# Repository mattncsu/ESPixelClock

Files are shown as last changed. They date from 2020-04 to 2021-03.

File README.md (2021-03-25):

# ESPixelClock
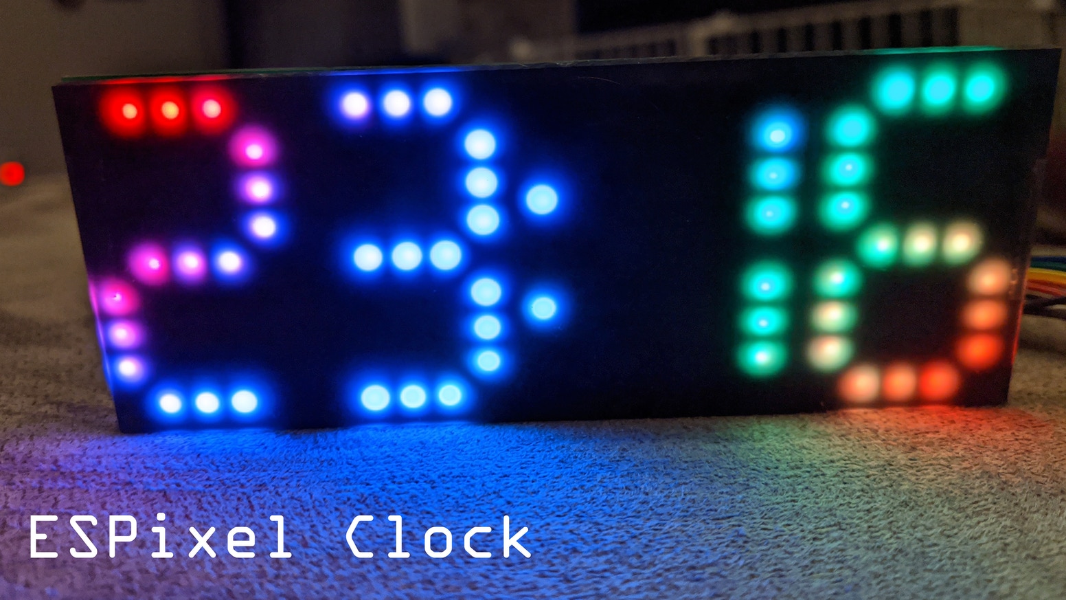
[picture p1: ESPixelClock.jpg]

Collection of code examples for the ESPixelClock

[This](https://github.com/mattncsu/ESPixelClock/tree/master/examples/ESPixelClock) is the code that comes pre-flashed on clocks that shipped with an ESP32 attached.

For those starting off with a bare board, I recommend taking a look at the examples in the [simple](https://github.com/mattncsu/ESPixelClock/tree/master/examples/simple) folder because they'll be easier to adapt to other microcontrollers.

ESP-ready version is now available on Amazon: https://www.amazon.com/ESPixel-Pixel-Based-Segment-Display-Raspberry/dp/B08TGLGM2F 
ESP-32 included version on Amazon: https://www.amazon.com/ESPixel-Clock-Pixel-Based-Segment-Display/dp/B08XQ449VJ

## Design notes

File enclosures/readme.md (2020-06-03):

Here is a place to post cases, enclosures, and other miscellaneous bits.

[DXF](hardware/Neo7Segment3535.dxf) and [STL](hardware/ESPixelClock_Board.stl) files are posted in the hardware folder to facilitate new designs.

[Light Diffuser](https://www.thingiverse.com/thing:4218698): This offsets the LEDs from the opaqe screen a bit causing the individual pixels to blur together:
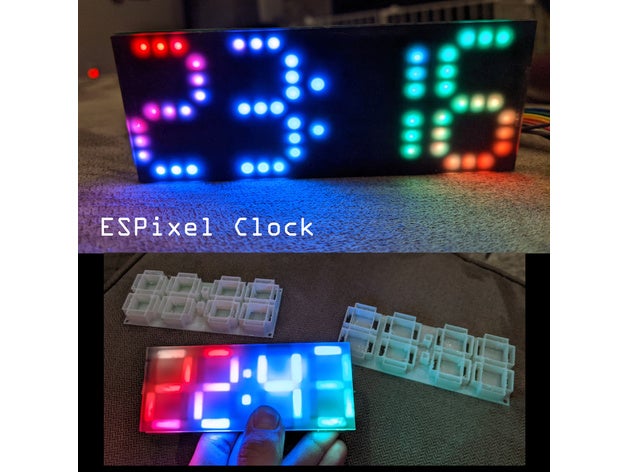
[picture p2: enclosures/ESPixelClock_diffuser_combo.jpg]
diffuser


[Simple Enclosure](https://www.thingiverse.com/thing:4145818): Simple enclosure design by Jason Coon:


[ESPixelClock Case](https://www.thingiverse.com/thing:4355887): Nice design by Tedder:


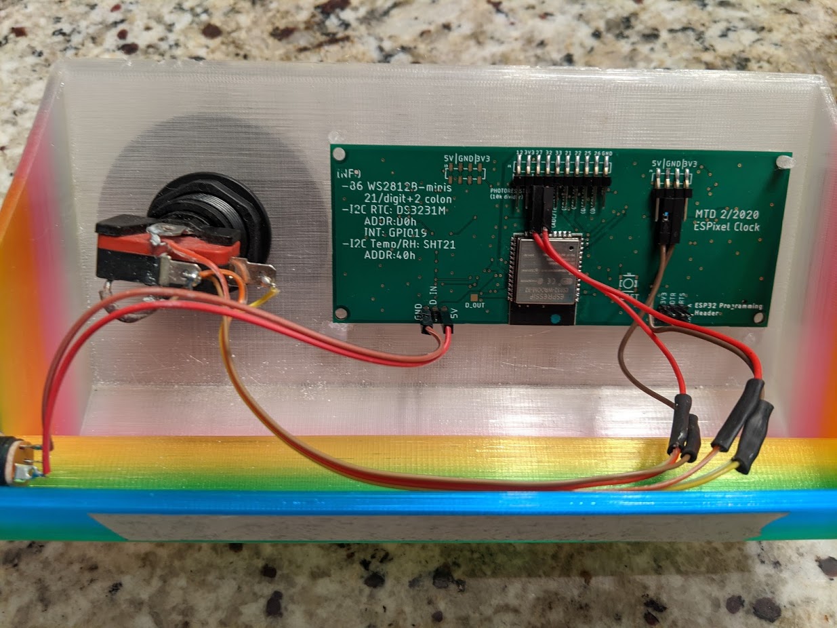
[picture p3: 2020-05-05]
examples/ESPixelClock/ESPixelClock_timer.jpg

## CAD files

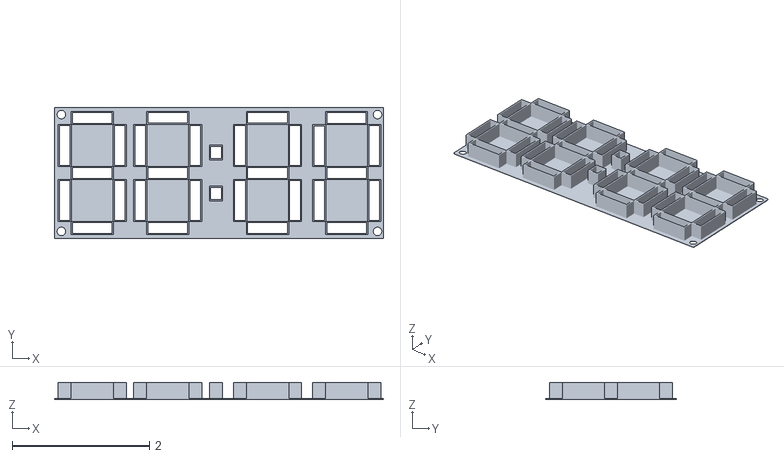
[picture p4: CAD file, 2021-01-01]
enclosures/ESPixelClockDiffuser1.stl
4.79 x 1.90 x 0.254

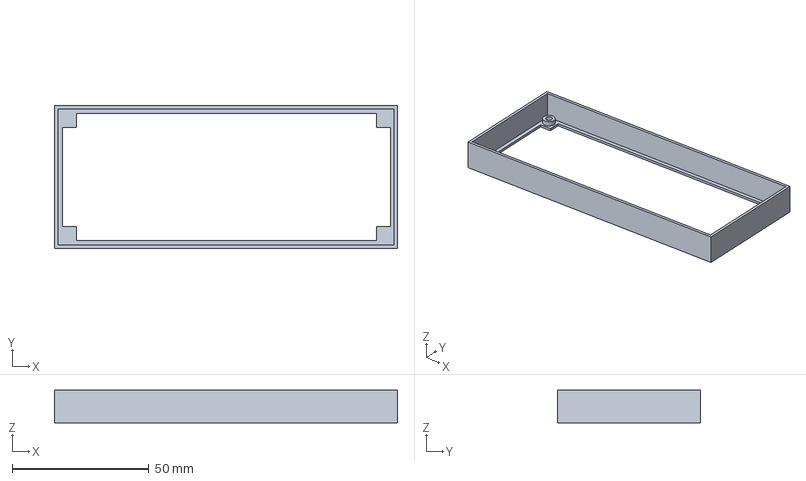
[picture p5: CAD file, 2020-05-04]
examples/ESPixelClock/hardware/ESPixel Clock Enclosure.3mf
125.6 x 52.2 x 12.0 mm

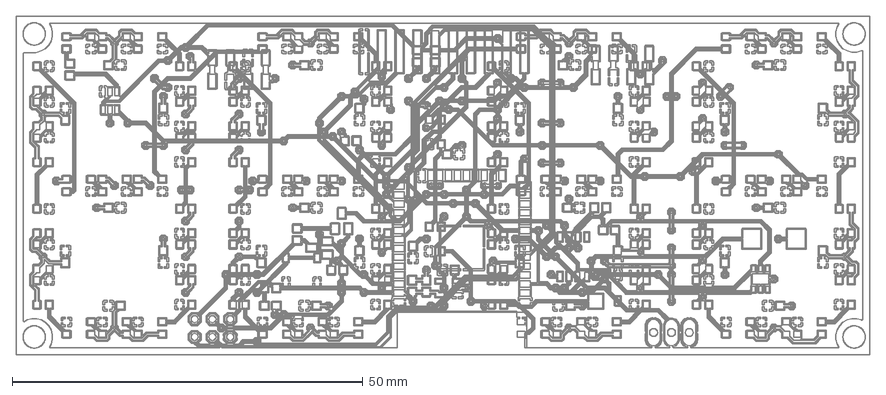
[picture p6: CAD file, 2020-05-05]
hardware/Neo7Segment3535.dxf
121.6 x 48.2 mm

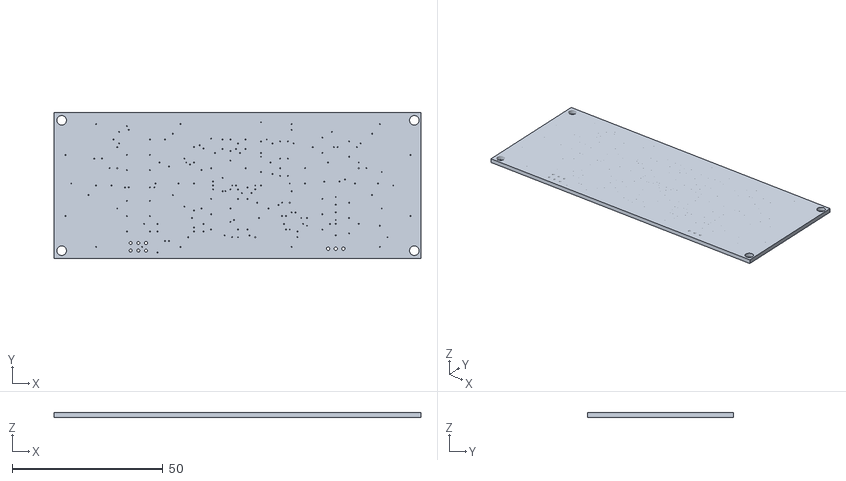
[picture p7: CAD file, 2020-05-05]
hardware/ESPixelClock_Board.stl
121.6 x 48.2 x 1.57

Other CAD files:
enclosures/Light_Guide_v5.f3z
examples/ESPixelClock/hardware/ESPixel Clock Enclosure.stl

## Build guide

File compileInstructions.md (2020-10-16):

This document is intended to describe the steps needed to compile and upload modified firmware to the ESPixelClock
Note that it is currently a work in progress, and may not be comprehensive, but should provide a good starting point at least.

Follow these instructions to install the ESP32 boards into the arduino IDE, https://github.com/espressif/arduino-esp32/blob/master/docs/arduino-ide/boards_manager.md

Set the board to "ESP32 Dev module" in the Boards Menu,

install the required libraries, including (but not necessarily limited to)
- FastLED.h
- AsyncTCP.h
- ESPAsyncWebServer.h
- AsyncElegantOTA.h
- DS3231M.h
- SHT21.h

Compile code to verify changes,

Then Go to the _Sketch_ menu > and click _Export Compiled Binary_

The web files are stored in the data subdirectory and uploaded to the file system of the clock. To update the files on the clock, use the ESP32 Sketch Data Upload plugin to generate a binary of the spiffs partition. Ignore errors about not being connected.  Watch the status messages for the path to the temporary binary files generated. On my machine, they were in C:\Users\<username>\AppData\Local\Temp\arduino_build_299134.

Upload the .bin file created using the web UI.

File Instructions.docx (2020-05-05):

Thank you for ordering an ESPixelClock and helping me bring this project to life! Here are a few things to get you started…

If you ordered a board with an ESP32 pre-soldered, it has already been flashed with the code located here: https://github.com/mattncsu/ESPixelClock/tree/master/examples/ESPixelClock

On power up, the clock will attempt to connect to a WiFi access point which will fail after 8 seconds since none is configured. The clock will then spin up an access point with the SSID ESPixelClock xx (where xx is the last two digits of the MAC address) with the password “espixelclock”. Connect to the hotspot and then open up a browser to http://192.168.1.1 or http://192.168.4.1 should the first address not work. Use the “Wifi Config” tab to set the SSID. After hitting submit, the clock will reboot and try to connect to your access point. Use your router’s network map page, an app like Fing to scan your network to find the new IP address or connect a usb-serial adapter to the TXD and GND pins to listen to debug messages from the clock.

For programming, you can compile a sketch and upload it using the Firmware upload page (http://<ip address>/update) or upload it over serial. Any USB-serial adapter with RTS/DTR pins will work. I personally use one like this https://www.amazon.com/CP2102-Multi-Function-Serial-Converter-Compatible/dp/B08246HWJ4/.

For the bare board, simply connect the microcontroller of your choice to the D_IN pad. Board can be powered from any of the 5V pins and may also run on 3.3V.

Specifications:

- LEDs: 86 x WS2812B-mini 3535 addressable LEDS
- RTC: DS3231M at I2C address 0x68 (silkscreen has typo) with capacitor backup
- Environment Sensor: SHT21 at I2C address 0x40

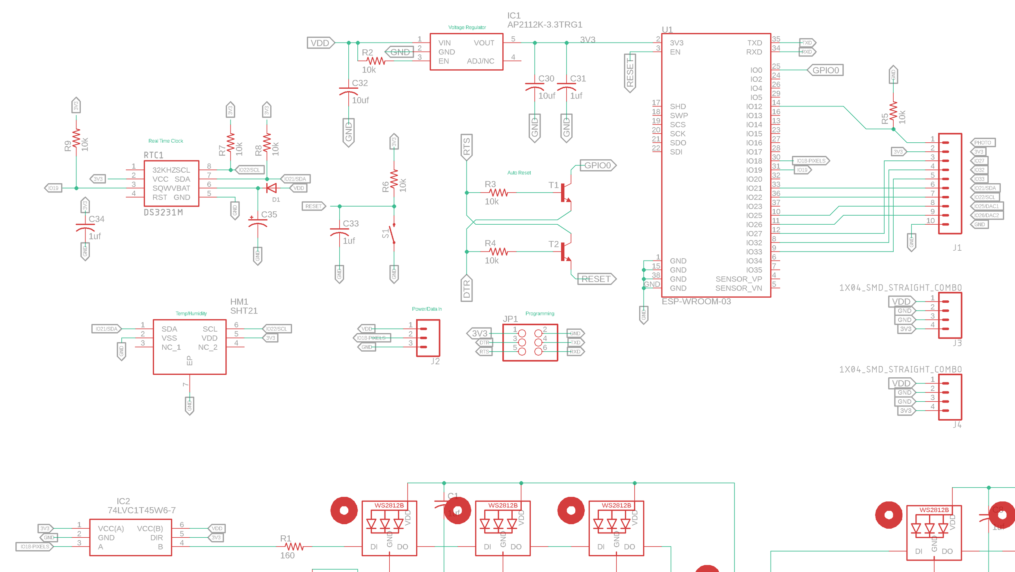
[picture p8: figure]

See https://github.com/mattncsu/ESPixelClock/tree/master/hardware for full schematic/layout

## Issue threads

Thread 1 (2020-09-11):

Instructions for compiling firmware for wireless upload?

Patronics, 2020-09-11:
Could you provide instructions (or a link to some) for how to compile the firmware to upload to the clock?
I've programmed a slight modification to add an option to hide the leading zero digit from the display, which I'll submit as a pull request once I figure out how to compile it and verify that it works.

Did you use the Arduino IDE directly, or PlatformIO, or something else? Any instructions or tips would be appreciated.

Patronics, 2020-09-11:
I figured it out, but this project could still benefit from instructions and a list of required libraries.
Here's a start at documenting the requirements:

Follow these instructions to install the ESP32 boards into the arduino IDE, https://github.com/espressif/arduino-esp32/blob/master/docs/arduino-ide/boards_manager.md

install the required libraries, including (but not necessarily limited to)

- FastLED.h
- AsyncTCP.h
- ESPAsyncWebServer.h
- AsyncElegantOTA.h

Compile code to verify changes,

Then Go to the _Sketch_ menu > and click _Export Compiled Binary_
Upload the .bin file created using the web UI

mattncsu, 2020-09-12:
That about sums it up, glad you got it working!

Closed 2020-09-13.

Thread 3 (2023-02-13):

missing ESPmDNS

digitongithub, 2023-02-13:
Missing ESPmDNS lib

mattncsu, 2023-02-13:
https://github.com/espressif/arduino-esp32/blob/master/libraries/ESPmDNS/src/ESPmDNS.h  ?

digitongithub, 2023-02-13:
Thanx, only too bad that the code gives a error : Compilation error: exit status 1

mattncsu, 2023-02-13:
Can you provide more information? Perhaps paste the whole error? (see [this](https://support.arduino.cc/hc/en-us/articles/6554914611228-Compilation-error-exit-status-1) as a reference)

digitongithub, 2023-02-13:
Many thanx. By this.

Using board 'nodemcuv2' from platform in folder: C:\Users\digiton\AppData\Local\Arduino15\packages\esp8266\hardware\esp8266\3.1.1
Using core 'esp8266' from platform in folder: C:\Users\digiton\AppData\Local\Arduino15\packages\esp8266\hardware\esp8266\3.1.1
"C:\\Users\\digiton\\AppData\\Local\\Arduino15\\packages\\esp8266\\tools\\python3\\3.7.2-post1/python3" -I "C:\\Users\\digiton\\AppData\\Local\\Arduino15\\packages\\esp8266\\hardware\\esp8266\\3.1.1/tools/mkbuildoptglobals.py" "C:\\Program Files\\Arduino IDE\\resources\\app\\node_modules\\arduino-ide-extension\\build" 10607 "C:\\Users\\digiton\\AppData\\Local\\Temp\\arduino-sketch-B9335CE627A45B552499B960B9FB2BB0" "C:\\Users\\digiton\\AppData\\Local\\Temp\\arduino-sketch-B9335CE627A45B552499B960B9FB2BB0/core/build.opt" "D:\\Documents\\Arduino\\Neo7SegmentClock-test/Neo7SegmentClock-test.ino.globals.h" "C:\\Users\\digiton\\AppData\\Local\\Arduino15\\packages\\esp8266\\hardware\\esp8266\\3.1.1\\cores\\esp8266/CommonHFile.h"
Clean build, created dir C:\Users\digiton\AppData\Local\Temp\arduino-sketch-B9335CE627A45B552499B960B9FB2BB0\core
Note: optional global include file 'D:\Documents\Arduino\Neo7SegmentClock-test\Neo7SegmentClock-test.ino.globals.h' does not exist.
  Read more at https://arduino-esp8266.readthedocs.io/en/latest/faq/a06-global-build-options.html
Detecting libraries used...
"C:\\Users\\digiton\\AppData\\Local\\Arduino15\\packages\\esp8266\\tools\\xtensa-lx106-elf-gcc\\3.1.0-gcc10.3-e5f9fec/bin/xtensa-lx106-elf-g++" -D__ets__ -DICACHE_FLASH -U__STRICT_ANSI__ -D_GNU_SOURCE -DESP8266 "@C:\\Users\\digiton\\AppData\\Local\\Temp\\arduino-sketch-B9335CE627A45B552499B960B9FB2BB0/core/build.opt" "-IC:\\Users\\digiton\\AppData\\Local\\Arduino15\\packages\\esp8266\\hardware\\esp8266\\3.1.1/tools/sdk/include" "-IC:\\Users\\digiton\\AppData\\Local\\Arduino15\\packages\\esp8266\\hardware\\esp8266\\3.1.1/tools/sdk/lwip2/include" "-IC:\\Users\\digiton\\AppData\\Local\\Arduino15\\packages\\esp8266\\hardware\\esp8266\\3.1.1/tools/sdk/libc/xtensa-lx106-elf/include" "-IC:\\Users\\digiton\\AppData\\Local\\Temp\\arduino-sketch-B9335CE627A45B552499B960B9FB2BB0/core" -c "@C:\\Users\\digiton\\AppData\\Local\\Arduino15\\packages\\esp8266\\hardware\\esp8266\\3.1.1/tools/warnings/none-g++" -Os -g -free -fipa-pta -Werror=return-type -mlongcalls -mtext-section-literals -fno-rtti -falign-functions=4 -std=gnu++17 -ffunction-sections -fdata-sections -fno-exceptions -DMMU_IRAM_SIZE=0x8000 -DMMU_ICACHE_SIZE=0x8000 -w -x c++ -E -CC -DNONOSDK22x_190703=1 -DF_CPU=80000000L -DLWIP_OPEN_SRC -DTCP_MSS=536 -DLWIP_FEATURES=1 -DLWIP_IPV6=0 -DARDUINO=10607 -DARDUINO_ESP8266_NODEMCU_ESP12E -DARDUINO_ARCH_ESP8266 "-DARDUINO_BOARD=\"ESP8266_NODEMCU_ESP12E\"" "-DARDUINO_BOARD_ID=\"nodemcuv2\"" -DLED_BUILTIN=2 -DFLASHMODE_DIO "-IC:\\Users\\digiton\\AppData\\Local\\Arduino15\\packages\\esp8266\\hardware\\esp8266\\3.1.1\\cores\\esp8266" "-IC:\\Users\\digiton\\AppData\\Local\\Arduino15\\packages\\esp8266\\hardware\\esp8266\\3.1.1\\variants\\nodemcu" "C:\\Users\\digiton\\AppData\\Local\\Temp\\arduino-sketch-B9335CE627A45B552499B960B9FB2BB0\\sketch\\Neo7SegmentClock-test.ino.cpp" -o nul
Alternatives for FastLED.h: [FastLED@3.5.0 FastLED@3.5.0]
ResolveLibrary(FastLED.h)
  -> candidates: [FastLED@3.5.0 FastLED@3.5.0]
"C:\\Users\\digiton\\AppData\\Local\\Arduino15\\packages\\esp8266\\tools\\xtensa-lx106-elf-gcc\\3.1.0-gcc10.3-e5f9fec/bin/xtensa-lx106-elf-g++" -D__ets__ -DICACHE_FLASH -U__STRICT_ANSI__ -D_GNU_SOURCE -DESP8266 "@C:\\Users\\digiton\\AppData\\Local\\Temp\\arduino-sketch-B9335CE627A45B552499B960B9FB2BB0/core/build.opt" "-IC:\\Users\\digiton\\AppData\\Local\\Arduino15\\packages\\esp8266\\hardware\\esp8266\\3.1.1/tools/sdk/include" "-IC:\\Users\\digiton\\AppData\\Local\\Arduino15\\packages\\esp8266\\hardware\\esp8266\\3.1.1/tools/sdk/lwip2/include" "-IC:\\Users\\digiton\\AppData\\Local\\Arduino15\\packages\\esp8266\\hardware\\esp8266\\3.1.1/tools/sdk/libc/xtensa-lx106-elf/include" "-IC:\\Users\\digiton\\AppData\\Local\\Temp\\arduino-sketch-B9335CE627A45B552499B960B9FB2BB0/core" -c "@C:\\Users\\digiton\\AppData\\Local\\Arduino15\\packages\\esp8266\\hardware\\esp8266\\3.1.1/tools/warnings/none-g++" -Os -g -free -fipa-pta -Werror=return-type -mlongcalls -mtext-section-literals -fno-rtti -falign-functions=4 -std=gnu++17 -ffunction-sections -fdata-sections -fno-exceptions -DMMU_IRAM_SIZE=0x8000 -DMMU_ICACHE_SIZE=0x8000 -w -x c++ -E -CC -DNONOSDK22x_190703=1 -DF_CPU=80000000L -DLWIP_OPEN_SRC -DTCP_MSS=536 -DLWIP_FEATURES=1 -DLWIP_IPV6=0 -DARDUINO=10607 -DARDUINO_ESP8266_NODEMCU_ESP12E -DARDUINO_ARCH_ESP8266 "-DARDUINO_BOARD=\"ESP8266_NODEMCU_ESP12E\"" "-DARDUINO_BOARD_ID=\"nodemcuv2\"" -DLED_BUILTIN=2 -DFLASHMODE_DIO "-IC:\\Users\\digiton\\AppData\\Local\\Arduino15\\packages\\esp8266\\hardware\\esp8266\\3.1.1\\cores\\esp8266" "-IC:\\Users\\digiton\\AppData\\Local\\Arduino15\\packages\\esp8266\\hardware\\esp8266\\3.1.1\\variants\\nodemcu" "-Id:\\Documents\\Arduino\\libraries\\FastLED\\src" "C:\\Users\\digiton\\AppData\\Local\\Temp\\arduino-sketch-B9335CE627A45B552499B960B9FB2BB0\\sketch\\Neo7SegmentClock-test.ino.cpp" -o nul
Alternatives for WiFi.h: [WiFi@1.2.7 WiFiNINA@1.8.13]
ResolveLibrary(WiFi.h)
  -> candidates: [WiFi@1.2.7 WiFiNINA@1.8.13]
"C:\\Users\\digiton\\AppData\\Local\\Arduino15\\packages\\esp8266\\tools\\xtensa-lx106-elf-gcc\\3.1.0-gcc10.3-e5f9fec/bin/xtensa-lx106-elf-g++" -D__ets__ -DICACHE_FLASH -U__STRICT_ANSI__ -D_GNU_SOURCE -DESP8266 "@C:\\Users\\digiton\\AppData\\Local\\Temp\\arduino-sketch-B9335CE627A45B552499B960B9FB2BB0/core/build.opt" "-IC:\\Users\\digiton\\AppData\\Local\\Arduino15\\packages\\esp8266\\hardware\\esp8266\\3.1.1/tools/sdk/include" "-IC:\\Users\\digiton\\AppData\\Local\\Arduino15\\packages\\esp8266\\hardware\\esp8266\\3.1.1/tools/sdk/lwip2/include" "-IC:\\Users\\digiton\\AppData\\Local\\Arduino15\\packages\\esp8266\\hardware\\esp8266\\3.1.1/tools/sdk/libc/xtensa-lx106-elf/include" "-IC:\\Users\\digiton\\AppData\\Local\\Temp\\arduino-sketch-B9335CE627A45B552499B960B9FB2BB0/core" -c "@C:\\Users\\digiton\\AppData\\Local\\Arduino15\\packages\\esp8266\\hardware\\esp8266\\3.1.1/tools/warnings/none-g++" -Os -g -free -fipa-pta -Werror=return-type -mlongcalls -mtext-section-literals -fno-rtti -falign-functions=4 -std=gnu++17 -ffunction-sections -fdata-sections -fno-exceptions -DMMU_IRAM_SIZE=0x8000 -DMMU_ICACHE_SIZE=0x8000 -w -x c++ -E -CC -DNONOSDK22x_190703=1 -DF_CPU=80000000L -DLWIP_OPEN_SRC -DTCP_MSS=536 -DLWIP_FEATURES=1 -DLWIP_IPV6=0 -DARDUINO=10607 -DARDUINO_ESP8266_NODEMCU_ESP12E -DARDUINO_ARCH_ESP8266 "-DARDUINO_BOARD=\"ESP8266_NODEMCU_ESP12E\"" "-DARDUINO_BOARD_ID=\"nodemcuv2\"" -DLED_BUILTIN=2 -DFLASHMODE_DIO "-IC:\\Users\\digiton\\AppData\\Local\\Arduino15\\packages\\esp8266\\hardware\\esp8266\\3.1.1\\cores\\esp8266" "-IC:\\Users\\digiton\\AppData\\Local\\Arduino15\\packages\\esp8266\\hardware\\esp8266\\3.1.1\\variants\\nodemcu" "-Id:\\Documents\\Arduino\\libraries\\FastLED\\src" "-Id:\\Documents\\Arduino\\libraries\\WiFi\\src" "C:\\Users\\digiton\\AppData\\Local\\Temp\\arduino-sketch-B9335CE627A45B552499B960B9FB2BB0\\sketch\\Neo7SegmentClock-test.ino.cpp" -o nul
Alternatives for ESPmDNS.h: [ESPmDNS@2.0.0]
ResolveLibrary(ESPmDNS.h)
  -> candidates: [ESPmDNS@2.0.0]
"C:\\Users\\digiton\\AppData\\Local\\Arduino15\\packages\\esp8266\\tools\\xtensa-lx106-elf-gcc\\3.1.0-gcc10.3-e5f9fec/bin/xtensa-lx106-elf-g++" -D__ets__ -DICACHE_FLASH -U__STRICT_ANSI__ -D_GNU_SOURCE -DESP8266 "@C:\\Users\\digiton\\AppData\\Local\\Temp\\arduino-sketch-B9335CE627A45B552499B960B9FB2BB0/core/build.opt" "-IC:\\Users\\digiton\\AppData\\Local\\Arduino15\\packages\\esp8266\\hardware\\esp8266\\3.1.1/tools/sdk/include" "-IC:\\Users\\digiton\\AppData\\Local\\Arduino15\\packages\\esp8266\\hardware\\esp8266\\3.1.1/tools/sdk/lwip2/include" "-IC:\\Users\\digiton\\AppData\\Local\\Arduino15\\packages\\esp8266\\hardware\\esp8266\\3.1.1/tools/sdk/libc/xtensa-lx106-elf/include" "-IC:\\Users\\digiton\\AppData\\Local\\Temp\\arduino-sketch-B9335CE627A45B552499B960B9FB2BB0/core" -c "@C:\\Users\\digiton\\AppData\\Local\\Arduino15\\packages\\esp8266\\hardware\\esp8266\\3.1.1/tools/warnings/none-g++" -Os -g -free -fipa-pta -Werror=return-type -mlongcalls -mtext-section-literals -fno-rtti -falign-functions=4 -std=gnu++17 -ffunction-sections -fdata-sections -fno-exceptions -DMMU_IRAM_SIZE=0x8000 -DMMU_ICACHE_SIZE=0x8000 -w -x c++ -E -CC -DNONOSDK22x_190703=1 -DF_CPU=80000000L -DLWIP_OPEN_SRC -DTCP_MSS=536 -DLWIP_FEATURES=1 -DLWIP_IPV6=0 -DARDUINO=10607 -DARDUINO_ESP8266_NODEMCU_ESP12E -DARDUINO_ARCH_ESP8266 "-DARDUINO_BOARD=\"ESP8266_NODEMCU_ESP12E\"" "-DARDUINO_BOARD_ID=\"nodemcuv2\"" -DLED_BUILTIN=2 -DFLASHMODE_DIO "-IC:\\Users\\digiton\\AppData\\Local\\Arduino15\\packages\\esp8266\\hardware\\esp8266\\3.1.1\\cores\\esp8266" "-IC:\\Users\\digiton\\AppData\\Local\\Arduino15\\packages\\esp8266\\hardware\\esp8266\\3.1.1\\variants\\nodemcu" "-Id:\\Documents\\Arduino\\libraries\\FastLED\\src" "-Id:\\Documents\\Arduino\\libraries\\WiFi\\src" "-Id:\\Documents\\Arduino\\libraries\\ESPmDNS\\src" "C:\\Users\\digiton\\AppData\\Local\\Temp\\arduino-sketch-B9335CE627A45B552499B960B9FB2BB0\\sketch\\Neo7SegmentClock-test.ino.cpp" -o nul
Alternatives for IPv6Address.h: []
ResolveLibrary(IPv6Address.h)
  -> candidates: []
In file included from D:\Documents\Arduino\Neo7SegmentClock-test\Neo7SegmentClock-test.ino:18:
**d:\Documents\Arduino\libraries\ESPmDNS\src/ESPmDNS.h:45:10: fatal error: IPv6Address.h: No such file or directory
   45 | #include "IPv6Address.h"**
      |          ^~~~~~~~~~~~~~~
compilation terminated.
Multiple libraries were found for "FastLED.h"
  Used: D:\Documents\Arduino\libraries\FastLED
  Not used: D:\Documents\Arduino\libraries\FastLED-master
Multiple libraries were found for "WiFi.h"
  Used: D:\Documents\Arduino\libraries\WiFi
  Not used: D:\Documents\Arduino\libraries\WiFiNINA
Using library FastLED at version 3.5.0 in folder: D:\Documents\Arduino\libraries\FastLED
Using library WiFi at version 1.2.7 in folder: D:\Documents\Arduino\libraries\WiFi
Using library ESPmDNS at version 2.0.0 in folder: D:\Documents\Arduino\libraries\ESPmDNS
exit status 1

Compilation error: exit status 1

mattncsu, 2023-02-13:
> Using board 'nodemcuv2' from platform in folder:

Looks like you have nodemcu selected as your board type. That is an ESP8266 based board which is why you are getting errors related to ESP8266. The ESPixelClock is an ESP32-based board. If you've already installed the ESP32 core for Arduino, change your board to the ESP32 dev board. If not follow these instructions to install the ESP32 core and then try again: https://lastminuteengineers.com/esp32-arduino-ide-tutorial/

digitongithub, 2023-02-13:
Thanx

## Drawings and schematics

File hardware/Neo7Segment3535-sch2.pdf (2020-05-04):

3V3 2 | EN 3 | SENSOR_VP | 4 SENSOR_VN | 5
IO23 | 37 IO22 | 36 TXD | 35 RXD | 34

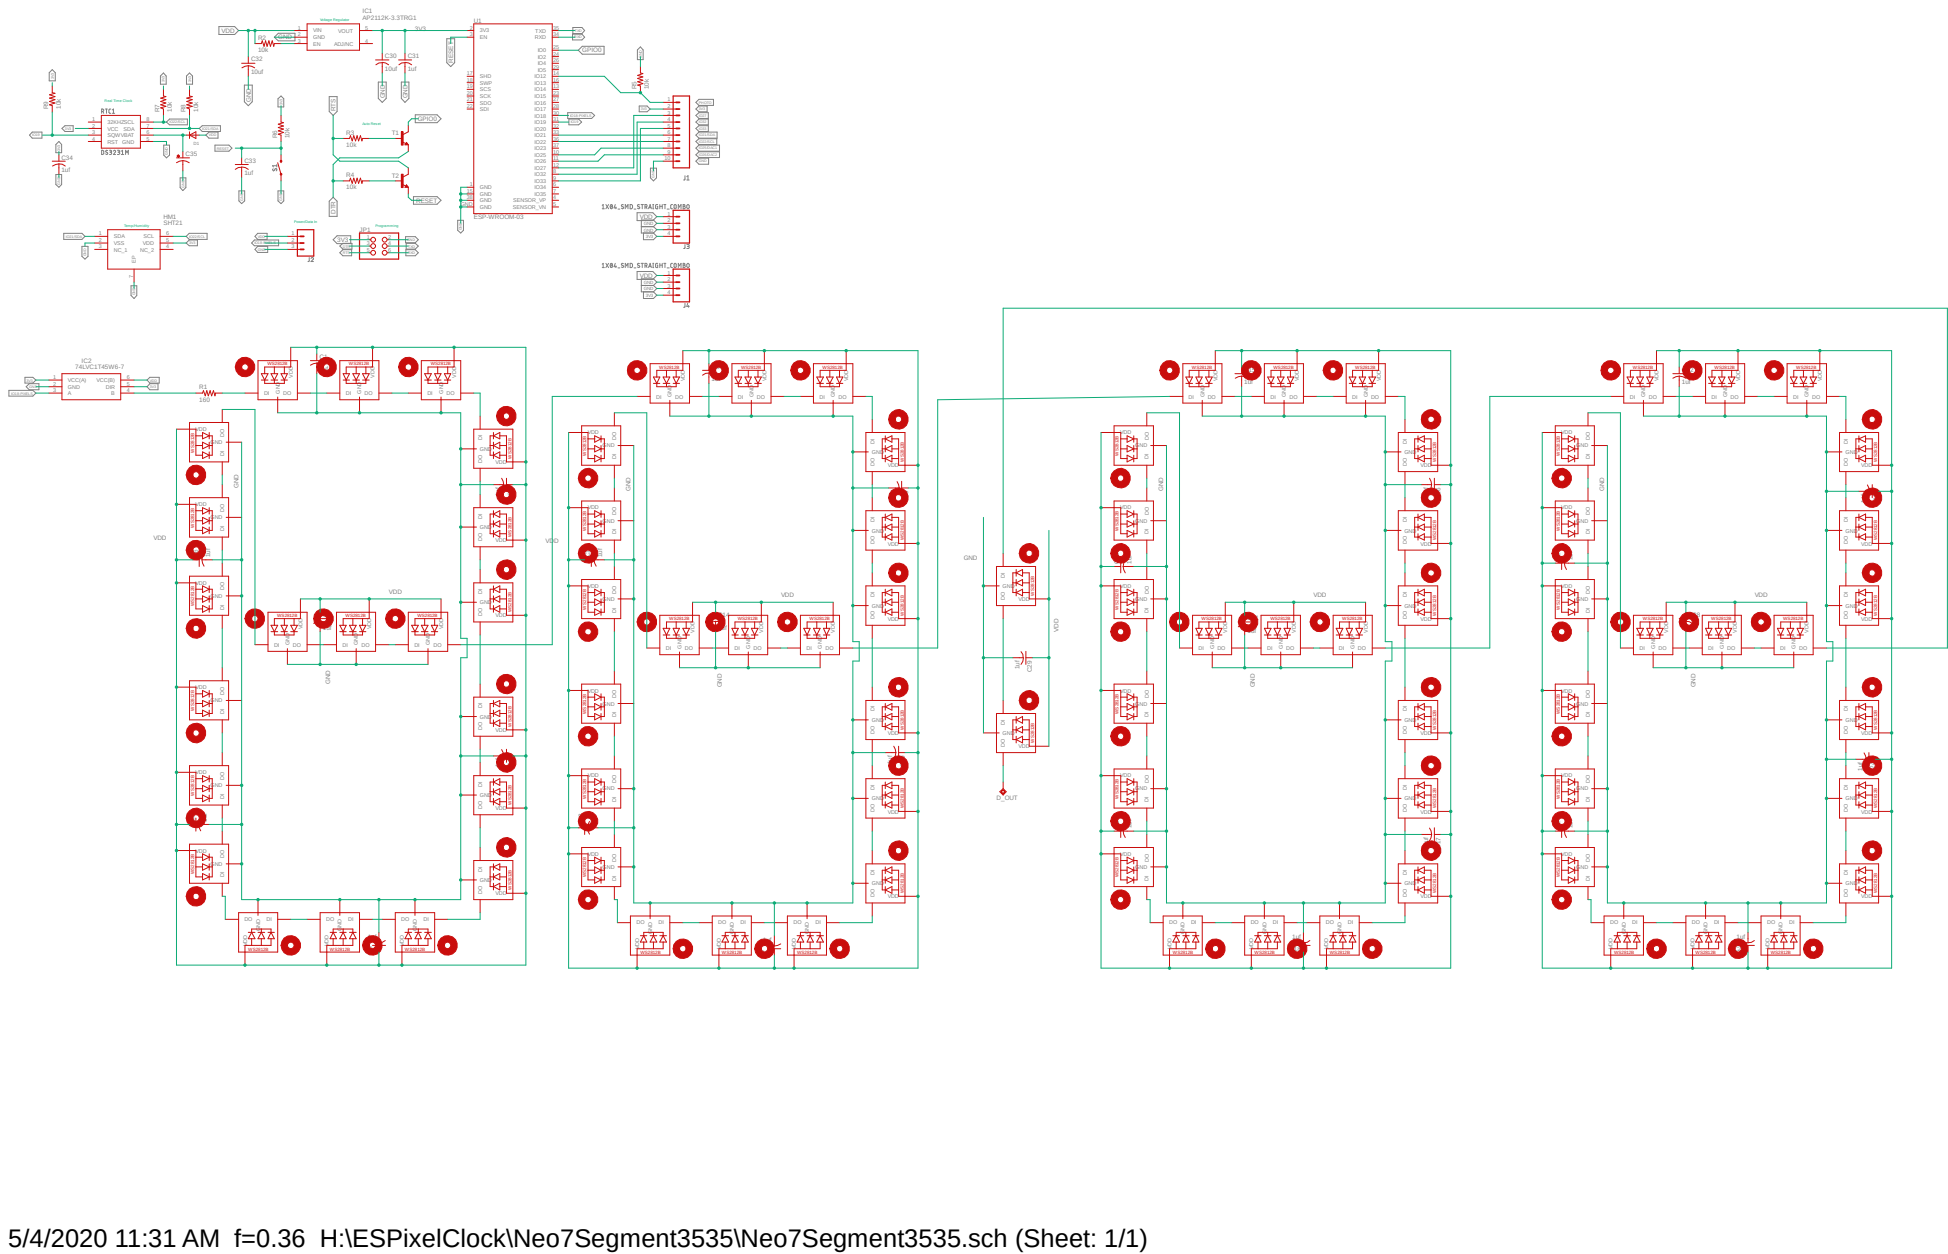
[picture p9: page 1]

7 SCL 6 VDD 5 NC_2 4HM1 D1 VCC(A) 1 GND 2 A

VDD DI GND DO

VDD DI GND DO VDD

5/4/2020 11:31 AM f=0.36 H:\ESPixelClock\Neo7Segment3535\Neo7Segment3535.sch (Sheet: 1/1)

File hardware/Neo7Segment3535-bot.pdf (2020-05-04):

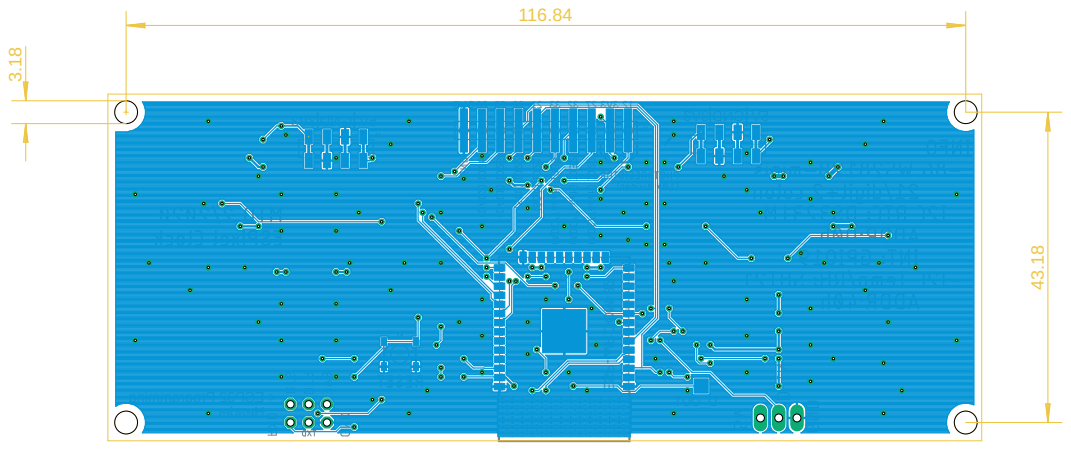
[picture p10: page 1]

DNG62 52 22 12 33 23 72 3V3 21 gni mmar gor P 23PSE < r edae H ESP-WROOM-32 3V3 DNG V5 3V3 DNG V5 1 U TUO_ D enoZt uopeeK 43.18 116.84 3.18

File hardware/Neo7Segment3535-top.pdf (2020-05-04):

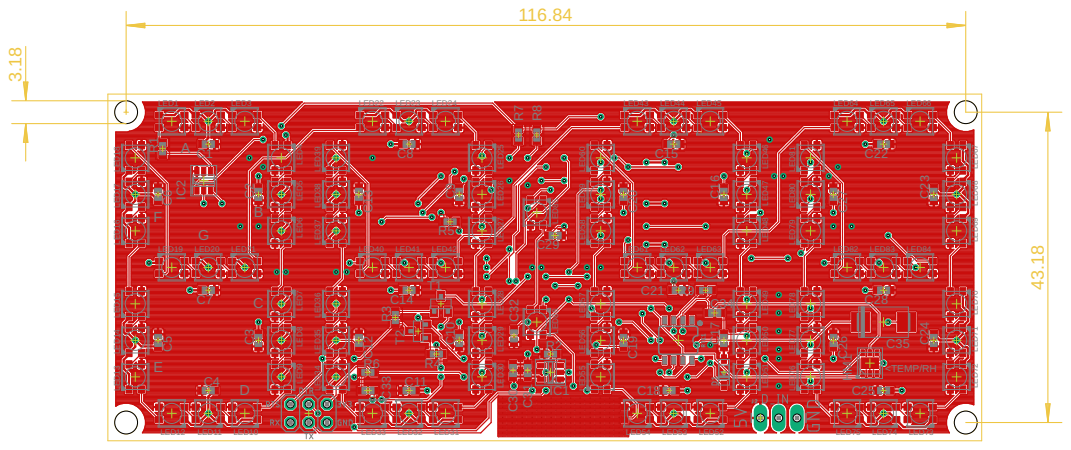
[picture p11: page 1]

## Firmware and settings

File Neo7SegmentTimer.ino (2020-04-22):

//***************************************************************
// A clock using pixels arranged in a 4-digit 7-segment display
//
//  This example uses 3 Pixels Per Segment (pps).
//  3pps x 7segments x 4digits + 2 digit colon = 86 pixels total
//
//
//  Based on 7Segment code by Marc Miller, (https://github.com/marmilicious/FastLED_examples/)
//  and ESP32 Simpletime example
//
//
//***************************************************************
#include <FastLED_NeoMatrix.h>
#include <FastLED.h>
#include "secrets.h" //defines ssid, password, and ntpServer as const char*
#include <WiFi.h>
#include <time.h>
#include <ESPmDNS.h>
#include <WiFiUdp.h>
#include <Hash.h>
#include <AsyncTCP.h>
#include <ESPAsyncWebServer.h>
#include <AsyncElegantOTA.h>


AsyncWebServer server(80);

CRGBPalette16 currentPalette;
TBlendType    currentBlending;

const long  gmtOffset_sec = -18000; //Eastern Time
const int   daylightOffset_sec = 3600;
bool colon,timerMode,countdownMode;
int countdown;

#define DATA_PIN    18
#define CLK_PIN     13
#define LED_TYPE    WS2812
#define COLOR_ORDER GRB
#define NUM_LEDS    86
#define BRIGHTNESS  10
#define FRAMES_PER_SECOND 100
#define LED_PIN     14
#define BTN_PIN     16
#define IDLE_TIME   5*60*1000

#define mw 25
#define mh 9
#define NUMMATRIX (mw*mh)
CRGB leds[NUMMATRIX];
// Define matrix width and height.
FastLED_NeoMatrix *matrix = new FastLED_NeoMatrix(leds, mw, mh, 
  NEO_MATRIX_TOP     + NEO_MATRIX_LEFT +
    NEO_MATRIX_ROWS + NEO_MATRIX_PROGRESSIVE);

//PCB Layout:
//    .0 .1 .2 .3 .4 .5 .6 .7 .8 .9 10 11.12 13 14 15 16 17 18 19 20 21 22 23 24
// 0  .. .0 .1 .2 .. .. .. 21 22 23 .. .. .. .. .. 42 43 44 .. .. .. 63 64 65 ..
// 1  17 .. .. .. .3 .. 38 .. .. .. 24 .. .. .. 59 .. .. .. 45 .. 80 .. .. .. 66
// 2  16 .. .. .. .4 .. 37 .. .. .. 25 .. 84 .. 58 .. .. .. 46 .. 79 .. .. .. 67
// 3  15 .. .. .. .5 .. 36 .. .. .. 26 .. .. .. 57 .. .. .. 47 .. 78 .. .. .. 68
// 4  .. 18 19 20 .. .. .. 39 40 41 .. .. .. .. .. 60 61 62 .. .. .. 81 82 83 ..
// 5  14 .. .. .. .6 .. 35 .. .. .. 27 .. .. .. 56 .. .. .. 48 .. 77 .. .. .. 69
// 6  13 .. .. .. .7 .. 34 .. .. .. 28 .. 85 .. 55 .. .. .. 49 .. 76 .. .. .. 70
// 7  12 .. .. .. .8 .. 33 .. .. .. 29 .. .. .. 54 .. .. .. 50 .. 75 .. .. .. 71
// 8  .. 11 10 .9 .. .. .. 32 31 30 .. .. .. .. .. 53 52 51 .. .. .. 74 73 72 ..    

uint16_t myRemapFn(uint16_t x, uint16_t y) {
    switch(y){
    case 0:
      switch(x){
          case 1: return 0;
          case 2: return 1;
          case 3: return 2;
          case 7: return 21;
          case 8: return 22;
          case 9: return 23;
          case 15: return 42;
          case 16: return 43;
          case 17: return 44;
          case 21: return 63;
          case 22: return 64;
          case 23: return 65;
          default: return 86;
      }
    
    case 1:
      switch(x){
        case 0: return 17;
        case 4: return 3;
        case 6: return 38;
        case 10: return 24;
        case 14: return 59;
        case 18: return 45;
        case 20: return 80;
        case 24: return 66;
        default: return 86;
      }
    case 2:
      switch(x){
        case 0: return 16;
        case 4: return 4;
        case 6: return 37;
        case 10: return 25;
        case 12: return 84;
        case 14: return 58;
        case 18: return 46;
        case 20: return 79;
        case 24: return 67;
        default: return 86;
      }   
    case 3:
      switch(x){
        case 0: return 15;
        case 4: return 5;
        case 6: return 36;
        case 10: return 26;
        case 14: return 57;
        case 18: return 47;
        case 20: return 78;
        case 24: return 68;
        default: return 86;
      }   
    case 4:
      switch(x){
          case 1: return 18;
          case 2: return 19;
          case 3: return 20;
          case 7: return 39;
          case 8: return 40;
          case 9: return 41;
          case 15: return 60;
          case 16: return 61;
          case 17: return 62;
          case 21: return 81;
          case 22: return 82;
          case 23: return 83;
          default: return 86;
      }   
    case 5:
      switch(x){
        case 0: return 14;
        case 4: return 6;
        case 6: return 35;
        case 10: return 27;
        case 14: return 56;
        case 18: return 48;
        case 20: return 77;
        case 24: return 69;
        default: return 86;
      }   
    case 6:
      switch(x){
        case 0: return 13;
        case 4: return 7;
        case 6: return 34;
        case 10: return 28;
        case 12: return 85;
        case 14: return 55;
        case 18: return 49;
        case 20: return 76;
        case 24: return 70;
        default: return 86;
      }   
    case 7:
      switch(x){
        case 0: return 12;
        case 4: return 8;
        case 6: return 33;
        case 10: return 29;
        case 14: return 54;
        case 18: return 50;
        case 20: return 75;
        case 24: return 71;
        default: return 86;
      }   
    case 8:
      switch(x){
          case 1: return 11;
          case 2: return 10;
          case 3: return 9;
          case 7: return 32;
          case 8: return 31;
          case 9: return 30;
          case 15: return 53;
          case 16: return 52;
          case 17: return 51;
          case 21: return 74;
          case 22: return 73;
          case 23: return 72;
          default: return 86;
      }   
  } 
}

struct Button {
    const uint8_t PIN;
    bool pressed;
};
Button button1 = {BTN_PIN, false};

void IRAM_ATTR isr(void* arg) {
  static unsigned long last_interrupt_time = 0;
  unsigned long interrupt_time = millis();
  // If interrupts come faster than 200ms, assume it's a bounce and ignore
  if (interrupt_time - last_interrupt_time > 200)
  {
    Button* s = static_cast<Button*>(arg);
    s->pressed = true;
  }
  last_interrupt_time = interrupt_time;
    
}

uint8_t pps = 3;  // number of Pixels Per Segment
CHSV segBlack(0,0,0); //black

//CRGBArray<NUM_LEDS> leds;

// Name segments and define pixel ranges.
//     1....2....3....4
//    AAA
//   F   B
//    GGG   
//   E   C  
//    DDD

CRGBSet seg1A(  leds(pps*0,  pps-1+(pps*0)  ));
CRGBSet seg1B(  leds(pps*1,  pps-1+(pps*1)  ));
CRGBSet seg1C(  leds(pps*2,  pps-1+(pps*2)  ));
CRGBSet seg1D(  leds(pps*3,  pps-1+(pps*3)  ));
CRGBSet seg1E(  leds(pps*4,  pps-1+(pps*4)  ));
CRGBSet seg1F(  leds(pps*5,  pps-1+(pps*5)  ));
CRGBSet seg1G(  leds(pps*6,  pps-1+(pps*6)  ));

CRGBSet seg2A(  leds(pps*0+(1*7*pps),  pps-1+(pps*0)+(1*7*pps)  ));
CRGBSet seg2B(  leds(pps*1+(1*7*pps),  pps-1+(pps*1)+(1*7*pps)  ));
CRGBSet seg2C(  leds(pps*2+(1*7*pps),  pps-1+(pps*2)+(1*7*pps)  ));
CRGBSet seg2D(  leds(pps*3+(1*7*pps),  pps-1+(pps*3)+(1*7*pps)  ));
CRGBSet seg2E(  leds(pps*4+(1*7*pps),  pps-1+(pps*4)+(1*7*pps)  ));
CRGBSet seg2F(  leds(pps*5+(1*7*pps),  pps-1+(pps*5)+(1*7*pps)  ));
CRGBSet seg2G(  leds(pps*6+(1*7*pps),  pps-1+(pps*6)+(1*7*pps)  ));

CRGBSet seg3A(  leds(pps*0+(2*7*pps),  pps-1+(pps*0)+(2*7*pps)  ));
CRGBSet seg3B(  leds(pps*1+(2*7*pps),  pps-1+(pps*1)+(2*7*pps)  ));
CRGBSet seg3C(  leds(pps*2+(2*7*pps),  pps-1+(pps*2)+(2*7*pps)  ));
CRGBSet seg3D(  leds(pps*3+(2*7*pps),  pps-1+(pps*3)+(2*7*pps)  ));
CRGBSet seg3E(  leds(pps*4+(2*7*pps),  pps-1+(pps*4)+(2*7*pps)  ));
CRGBSet seg3F(  leds(pps*5+(2*7*pps),  pps-1+(pps*5)+(2*7*pps)  ));
CRGBSet seg3G(  leds(pps*6+(2*7*pps),  pps-1+(pps*6)+(2*7*pps)  ));

CRGBSet seg4A(  leds(pps*0+(3*7*pps),  pps-1+(pps*0)+(3*7*pps)  ));
CRGBSet seg4B(  leds(pps*1+(3*7*pps),  pps-1+(pps*1)+(3*7*pps)  ));
CRGBSet seg4C(  leds(pps*2+(3*7*pps),  pps-1+(pps*2)+(3*7*pps)  ));
CRGBSet seg4D(  leds(pps*3+(3*7*pps),  pps-1+(pps*3)+(3*7*pps)  ));
CRGBSet seg4E(  leds(pps*4+(3*7*pps),  pps-1+(pps*4)+(3*7*pps)  ));
CRGBSet seg4F(  leds(pps*5+(3*7*pps),  pps-1+(pps*5)+(3*7*pps)  ));
CRGBSet seg4G(  leds(pps*6+(3*7*pps),  pps-1+(pps*6)+(3*7*pps)  ));

CRGBSet col(leds(84,85)); //colon

int count = 8888;  // keeps track of what number to display


//---------------------------------------------------------------

void printLocalTime()
{
  struct tm timeinfo;
  if(!getLocalTime(&timeinfo)){
    Serial.println("Failed to obtain time");
    return;
  }
  Serial.println(&timeinfo, "%A, %B %d %Y %H:%M:%S");
  count=(timeinfo.tm_hour*100+timeinfo.tm_min);
}

//---------------------------------------------------------------
void setSegments(int count, uint8_t colorIndex){
  // Based on the current count set number segments on or off
  uint8_t c1 = 0;  // Variable to store 1s digit
  uint8_t c10 = 0;  // Variable to store 10s digit
  uint8_t c100 = 0;  // Variable to store 100s digit
  uint8_t c1000 = 0;  // Variable to store 100s digit
  int c;
  CHSV segCOLOR(0,0,0);

  c1 = count % 10;
  c10 = (count / 10) % 10;
  c100 = (count / 100) % 10;
  c1000 = (count / 1000) % 10;
    
//  Serial.print("count = "); Serial.print(count);  // Print to serial monitor current count
//  Serial.print("\t  1000s: "); Serial.print(c1000);  // Print 1000s digit
//  Serial.print("  100s: "); Serial.print(c100);  // Print 100s digit
//  Serial.print("   10s: "); Serial.print(c10);  // Print 10s digit
//  Serial.print("   1s: "); Serial.println(c1);  // Print 1s digit

     uint8_t brightness = 255;
     
     for( int i = 0; i < NUM_LEDS; i++) {
        leds[i] = ColorFromPalette( currentPalette, colorIndex, brightness, currentBlending);
        colorIndex += 3;
    }
    //next block of if statements sets segments to black to form digits
    segCOLOR = segBlack; //unused segment color
    if (c1000 == 0) { seg1G = segCOLOR; }
    if (c1000 == 1) { seg1A = seg1D = seg1E = seg1F = seg1G = segCOLOR; } 
    if (c1000 == 2) { seg1C = seg1F = segCOLOR; } 
    if (c1000 == 3) { seg1E = seg1F = segCOLOR; } 
    if (c1000 == 4) { seg1A = seg1D = seg1E = segCOLOR; } 
    if (c1000 == 5) { seg1B = seg1E = segCOLOR; } 
    if (c1000 == 6) { seg1B = segCOLOR; } //B
    if (c1000 == 7) { seg1D = seg1E = seg1F = seg1G = segCOLOR; } 
    if (c1000 == 8) {  }
    if (c1000 == 9) { seg1D = seg1E = segCOLOR; } 

    if (c100 == 0) { seg2G = segCOLOR; }
    if (c100 == 1) { seg2A = seg2D = seg2E = seg2F = seg2G = segCOLOR; } 
    if (c100 == 2) { seg2C = seg2F = segCOLOR; } 
    if (c100 == 3) { seg2E = seg2F = segCOLOR; } 
    if (c100 == 4) { seg2A = seg2D = seg2E = segCOLOR; } 
    if (c100 == 5) { seg2B = seg2E = segCOLOR; } 
    if (c100 == 6) { seg2B = segCOLOR; } //B
    if (c100 == 7) { seg2D = seg2E = seg2F = seg2G = segCOLOR; } 
    if (c100 == 8) {  }
    if (c100 == 9) { seg2D = seg2E = segCOLOR; } 

    if (c10 == 0) { seg3G = segCOLOR; }
    if (c10 == 1) { seg3A = seg3D = seg3E = seg3F = seg3G = segCOLOR; } 
    if (c10 == 2) { seg3C = seg3F = segCOLOR; } 
    if (c10 == 3) { seg3E = seg3F = segCOLOR; } 
    if (c10 == 4) { seg3A = seg3D = seg3E = segCOLOR; } 
    if (c10 == 5) { seg3B = seg3E = segCOLOR; } 
    if (c10 == 6) { seg3B = segCOLOR; } //B
    if (c10 == 7) { seg3D = seg3E = seg3F = seg3G = segCOLOR; } 
    if (c10 == 8) {  }
    if (c10 == 9) { seg3D = seg3E = segCOLOR; } 

    if (c1 == 0) { seg4G = segCOLOR; }
    if (c1 == 1) { seg4A = seg4D = seg4E = seg4F = seg4G = segCOLOR; } 
    if (c1 == 2) { seg4C = seg4F = segCOLOR; } 
    if (c1 == 3) { seg4E = seg4F = segCOLOR; } 
    if (c1 == 4) { seg4A = seg4D = seg4E = segCOLOR; } 
    if (c1 == 5) { seg4B = seg4E = segCOLOR; } 
    if (c1 == 6) { seg4B = segCOLOR; } //B
    if (c1 == 7) { seg4D = seg4E = seg4F = seg4G = segCOLOR; } 
    if (c1 == 8) {  }
    if (c1 == 9) { seg4D = seg4E = segCOLOR; } 


     if (colon){
//      col = colON; //comment out to use palette color
    } else {
      col = CRGB::Black; //turns off colon to make it blink
    }


}//end setSegments

void setup() {
  Serial.begin(115200);  // Allows serial monitor output
  pinMode(button1.PIN,INPUT_PULLUP);
  attachInterruptArg(button1.PIN, isr, &button1, FALLING);
  pinMode(15, OUTPUT); //Led pin GND
  digitalWrite(15,LOW); //ground LED pin
  pinMode(LED_PIN, OUTPUT);

  //connect to WiFi
  Serial.printf("Connecting to %s ", ssid);
  WiFi.mode(WIFI_STA);
  WiFi.begin(ssid, password);
  while (WiFi.status() != WL_CONNECTED) {
      delay(500);
      Serial.print(".");
  }
  Serial.print("Connected to ");
  Serial.println(ssid);
  Serial.print("IP address: ");
  Serial.println(WiFi.localIP());

 server.on("/", HTTP_GET, [](AsyncWebServerRequest *request) {
    request->send(200, "text/plain", "Hi! I am ESP32.");
  });

  AsyncElegantOTA.begin(&server);    // Start ElegantOTA
  server.begin();
  Serial.println("HTTP server started");

 
  
  //init and get the time
  configTime(gmtOffset_sec, daylightOffset_sec, ntpServer);
  printLocalTime();

  FastLED.addLeds<NEOPIXEL,PIN>(  leds, NUMMATRIX  ).setCorrection(TypicalLEDStrip);
//  FastLED.addLeds<LED_TYPE,DATA_PIN,COLOR_ORDER>(leds, NUM_LEDS).setCorrection(TypicalSMD5050);
  FastLED.setBrightness(BRIGHTNESS);
  matrix->begin();
  matrix->setTextWrap(false);
  matrix->setBrightness(BRIGHTNESS);
  matrix->setRemapFunction(myRemapFn);
  currentPalette = RainbowColors_p;
//  currentPalette = CloudColors_p;
//  currentPalette = PartyColors_p;
//  currentPalette = ForestColors_p;
//  currentPalette = OceanColors_p;
  currentBlending = LINEARBLEND;
  FastLED.clear();  // Initially clear all pixels
}

long startTime;

//---------------------------------------------------------------
void loop()
{
  AsyncElegantOTA.loop();

  if (button1.pressed) {
    Serial.printf("Button 1 has been pressed\n");
    button1.pressed = false;
    if (!timerMode){
      countdownMode=true;
      countdown=10;
      digitalWrite(LED_PIN,HIGH);
    } else {
      digitalWrite(LED_PIN,LOW);
      FastLED.delay(15000);
      timerMode=false;
    }
    
  }
  static uint8_t startIndex = 0;
  EVERY_N_MILLISECONDS(50){ //motion speed: increase delay to slow down
    startIndex = startIndex + 1;
  }
    setSegments(count,startIndex);  // Determine which segments are ON or OFF

  EVERY_N_MILLISECONDS(1000){
    colon = !colon; //flash the colon
    if(countdownMode && countdown==0){
      countdownMode=false;
      timerMode=true;
      startTime=millis();
      count=0;
    }
    if(countdownMode){
      countdown--;
    }
  }

  EVERY_N_MILLISECONDS(10){
    int x = millis() - startTime;
    if (countdownMode){
      count=countdown;
    }
    if (timerMode){
      if(x < 90000){
        count=(x)/10;
        colon=true;
      }
      else{
        count = (x/1000/60)*100 + (x/1000) % 60;
      }
      if (millis()-startTime>IDLE_TIME){
        timerMode=false;
      }
    }
  }

  EVERY_N_MILLISECONDS(250){
    if (timerMode){
      digitalWrite(LED_PIN,(!digitalRead(LED_PIN)));
    }
  }
  
  EVERY_N_MILLISECONDS(5000){
    if (!timerMode && !countdownMode){
      printLocalTime();
    }
  } 
  EVERY_N_MINUTES(5){
    configTime(gmtOffset_sec, daylightOffset_sec, ntpServer); //get fresh NTP time
  }
  FastLED.delay(1000/FRAMES_PER_SECOND); 

}

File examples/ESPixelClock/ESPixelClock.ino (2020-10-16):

/*
   ESPixelClock
   https://github.com/mattncsu/ESPixelClock

   



   Timezone codes from: https://github.com/jdlambert/micro_tz_db
   Based on:
   ESP32 FastLED WebServer: https://github.com/jasoncoon/esp32-fastled-webserver
   Copyright (C) 2017 Jason Coon

   Built upon the amazing FastLED work of Daniel Garcia and Mark Kriegsman:
   https://github.com/FastLED/FastLED

   ESP32 support provided by the hard work of Sam Guyer:
   https://github.com/samguyer/FastLED

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
   You should have received a copy of the GNU General Public License
   along with this program.  If not, see <http://www.gnu.org/licenses/>.
*/

#include <FastLED.h>
#include <WiFi.h>
#include "esp_wifi.h"
#include <FS.h>
#include <SPIFFS.h>
#include <EEPROM.h>
#include <Preferences.h>
#include <AsyncTCP.h>
#include <ESPAsyncWebServer.h>
#include <AsyncElegantOTA.h>

#include <time.h>
#include <DS3231M.h> //https://github.com/SV-Zanshin/DS3231M
#include <SHT21.h> //https://github.com/markbeee/SHT21
DS3231M_Class DS3231M;
SHT21 SHT21;
wifi_sta_list_t stationList; //Used to determine if anyone connected to softAP
Preferences preferences;
AsyncWebServer server(80); //for the update server

#if defined(FASTLED_VERSION) && (FASTLED_VERSION < 3001008)
#warning "Requires FastLED 3.1.8 or later; check github for latest code."
#endif

String ssid,password,tzInfo,ntpServer1,ntpServer2,clockName; 

int8_t timezoneOffset = -6; // Central Time
bool tzChanged=false;
int8_t temperatureOffset = 0;
long gmtOffset_sec = timezoneOffset * 3600;
const int daylightOffset_sec = 3600;

int16_t timeInt = 8888;  // keeps track of what number to display
bool colon = false;
bool timerMode,countdownMode;
int16_t countdown;
long startTime;
float temp,rh;
DateTime now;

#define LED_PIN     27 //LED from lighted switch
#define BTN_PIN     32 //Push button to start stop watch mode
#define IDLE_TIME   5*60*1000 //terminate stop watch mode after 5 minutes

uint8_t autoplay = 0;
uint8_t autoplayDuration = 10;
unsigned long autoPlayTimeout = 0;

uint8_t currentPatternIndex = 0; // Index number of which pattern is current

uint8_t gHue = 0; // rotating "base color" used by many of the patterns

uint8_t power = 1;
uint8_t leadingZeroEnabled = 1;
uint8_t blinkingColonEnabled = 1;
uint8_t time24 = 1;
uint8_t brightness = 8;

uint8_t speed = 30;

// COOLING: How much does the air cool as it rises?
// Less cooling = taller flames.  More cooling = shorter flames.
// Default 50, suggested range 20-100
uint8_t cooling = 50;

// SPARKING: What chance (out of 255) is there that a new spark will be lit?
// Higher chance = more roaring fire.  Lower chance = more flickery fire.
// Default 120, suggested range 50-200.
uint8_t sparking = 120;

CRGB solidColor = CRGB::Blue;

uint8_t cyclePalettes = 0;
uint8_t paletteDuration = 10;
uint8_t currentPaletteIndex = 3;
unsigned long paletteTimeout = 0;

#define ARRAY_SIZE(A) (sizeof(A) / sizeof((A)[0]))

#define DATA_PIN    18
#define LED_TYPE    WS2812B
#define COLOR_ORDER GRB
#define NUM_LEDS    86
CRGBArray<NUM_LEDS> leds;

#define MILLI_AMPS         2000 // IMPORTANT: set the max milli-Amps of your power supply (4A = 4000mA)
#define FRAMES_PER_SECOND  60

#include "patterns.h"
#include "field.h"
#include "fields.h"


#include "wifi.h"
#include "web.h"

// wifi ssid and password should be added to a file in the sketch named secrets.h
// the secrets.h file should be added to the .gitignore file and never committed or
// pushed to public source control (GitHub).
// const char* ssid = "........";
// const char* password = "........";

struct Button {
    const uint8_t PIN;
    bool pressed;
};
Button button1 = {BTN_PIN, false};

void IRAM_ATTR isr(void* arg) {
  static unsigned long last_interrupt_time = 0;
  unsigned long interrupt_time = millis();
  // If interrupts come faster than 200ms, assume it's a bounce and ignore
  if (interrupt_time - last_interrupt_time > 200)
  {
    Button* s = static_cast<Button*>(arg);
    s->pressed = true;
  }
  last_interrupt_time = interrupt_time;
    
}

void listDir(fs::FS &fs, const char * dirname, uint8_t levels) {
  Serial.printf("Listing directory: %s\n", dirname);

  File root = fs.open(dirname);
  if (!root) {
    Serial.println("Failed to open directory");
    return;
  }
  if (!root.isDirectory()) {
    Serial.println("Not a directory");
    return;
  }

  File file = root.openNextFile();
  while (file) {
    if (file.isDirectory()) {
      Serial.print("  DIR : ");
      Serial.println(file.name());
      if (levels) {
        listDir(fs, file.name(), levels - 1);
      }
    } else {
      Serial.print("  FILE: ");
      Serial.print(file.name());
      Serial.print("  SIZE: ");
      Serial.println(file.size());
    }
    file = root.openNextFile();
  }
}

void printLocalTime()
{
  
  setenv("TZ", tzInfo.c_str(), 1);
  tzset();
  now = DS3231M.now();

  //struct tm timeinfo;

  Serial.printf("%04d-%02d-%02d %02d:%02d:%02d Temp: %.1fC RH:%.1f%%  %s\n", now.year(),          // Use sprintf() to pretty print    //
          now.month(), now.day(), now.hour(), now.minute(), now.second(),
          temp, rh, tzInfo.c_str());  
  if (time24 == 0){
    if (now.hour() > 12){
      timeInt = (now.hour()-12)*100+now.minute();
    }
    else{
      timeInt = now.hour()*100+now.minute();
    }
  }
  else{
    timeInt = now.hour()*100+now.minute();
  }
}

void getNTPTime(){
  if ( WiFi.status() == WL_CONNECTED) {
    Serial.println("Getting NTP Time...");
    configTzTime(tzInfo.c_str(), ntpServer1.c_str(), ntpServer2.c_str()); //get fresh NTP time
    struct tm timeinfo;
    if(!getLocalTime(&timeinfo)){
      Serial.println("Failed to obtain NTP time");
      return;
    }
    Serial.println(&timeinfo, "NTP Time: %A, %B %d %Y %H:%M:%S");
    int hour = timeinfo.tm_hour;
    int minute  = timeinfo.tm_min;
    int second  = timeinfo.tm_sec;
    int day = timeinfo.tm_mday;
    int month = timeinfo.tm_mon + 1;
    int year = timeinfo.tm_year +1900;
    DS3231M.adjust(DateTime(year,month,day,hour,minute,second));      // Adjust the RTC date/time
    Serial.print(F("RTC time/date has been set.\n")); 
  
  } else {
    Serial.println("Can't get NTP time without WiFi...");
  }
}
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

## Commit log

2020-05-05 Add files via upload
    Changed temperature reading to every 5 minutes since it causes a brief stutter in the pattern display. Changed pin numbers for button/led to reflect current board design.
2020-05-05 Add files via upload
    Photo showing hardware configuration for timer example

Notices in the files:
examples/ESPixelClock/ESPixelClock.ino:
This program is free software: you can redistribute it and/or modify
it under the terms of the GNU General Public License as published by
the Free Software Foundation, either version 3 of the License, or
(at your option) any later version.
